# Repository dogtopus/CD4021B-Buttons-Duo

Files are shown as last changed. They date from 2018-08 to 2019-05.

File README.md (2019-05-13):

# CD4021B-Buttons-Duo

16 channel arcade button driver

(Legacy project, no longer in development)

## Features

- 16 channels
  - 8 channels for regular (NC and/or NO, depends on the software) buttons
  - 8 channels for illuminated (lamp equipped) buttons
- Programmable lamps
- Button interface are somewhat compatible with [CY-822B][1] encoder (shares
  the same electrical interface) with a better (not hard-wired to VBUS) lamp
  support.
- Separated lamp power rail (Supports 0-12V PSU, 500mA max for each channel)
- Supports 3.3V (at low speed like 1-2MHz) and 5V logic
- Supports controlling via SPI bus and bitbang with Arduino ShiftIn/ShiftOut
  code

## Usage

- Install KiCad
- Plot the board
- Zip the Gerber files and send them to whatever PCB house you like
- TODO components, BOM, etc.
- ???
- PROFIT!

PS: There's no plan for selling the assembled boards or kits at the moment,
so too bad for those who just want a working board :<

## Notes

- First and foremost, I am still very new to PCB layout and routing, so feel
  free to open an issue to give suggestions on my design and/or point out any
  mistakes I made.
- The JST connectors are rotated 180 degrees (so pin 1 is on the **right**
  side) due to a mistake I made at the very early stage of designing and the
  quickest way of fixing it is to rotate the connector.
- Make sure you are using the **"always on"** wiring suggested [here][1] (i.e.
  pin 1 is common ground, pin 2 is button and pin 3 is lamp)
  for illuminated buttons. Behavior on "illuminate on press" wiring (i.e.
  reversing pin 1 and pin 2) is undefined
  (and potentially dangerous if the lamps are powered with voltage higher or
  lower than VCC since this wiring basically shorts the lamp power to the button
  pin when the switch on the button is closed)
- The P-channel MOSFET can be swapped for cheaper alternative (e.g. CJL3415) as
  long as they have the same electrical interface, 
  the parameters (Vds, Vgs, Ids, Rds) are reasonable and proper zener diodes
  (D1-D8) and voltage divider (R1-R8, R9-R16) are chosen so that the gate of the
  MOSFET are not overdriven. (In case of CJL3415, a good choice would be 10k for
  R9-R16, 20k for R1-R8, and zeners with zener voltage of 7.5V)
  Also, TPIC6C596 can be used in place of TPIC6C595. (Tested)

[1]: https://cy-822b.blogspot.com/2016/08/the-cy-822b-usb-led-joystick-controller.html

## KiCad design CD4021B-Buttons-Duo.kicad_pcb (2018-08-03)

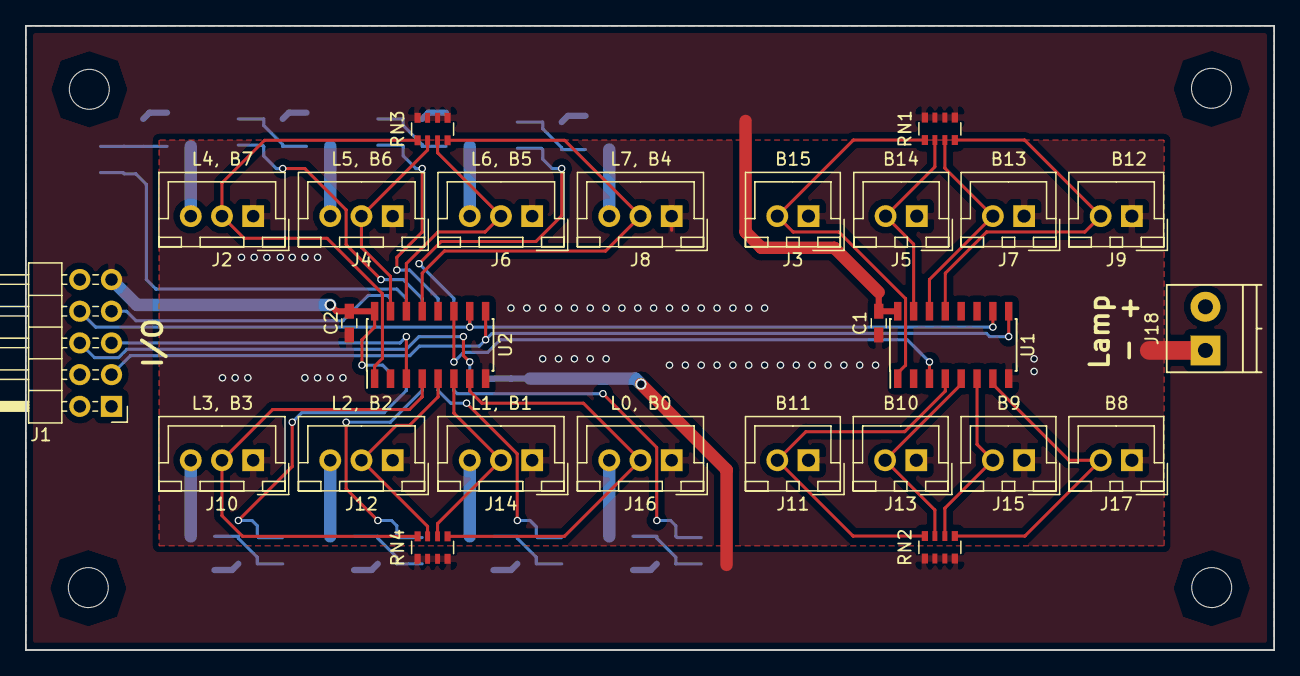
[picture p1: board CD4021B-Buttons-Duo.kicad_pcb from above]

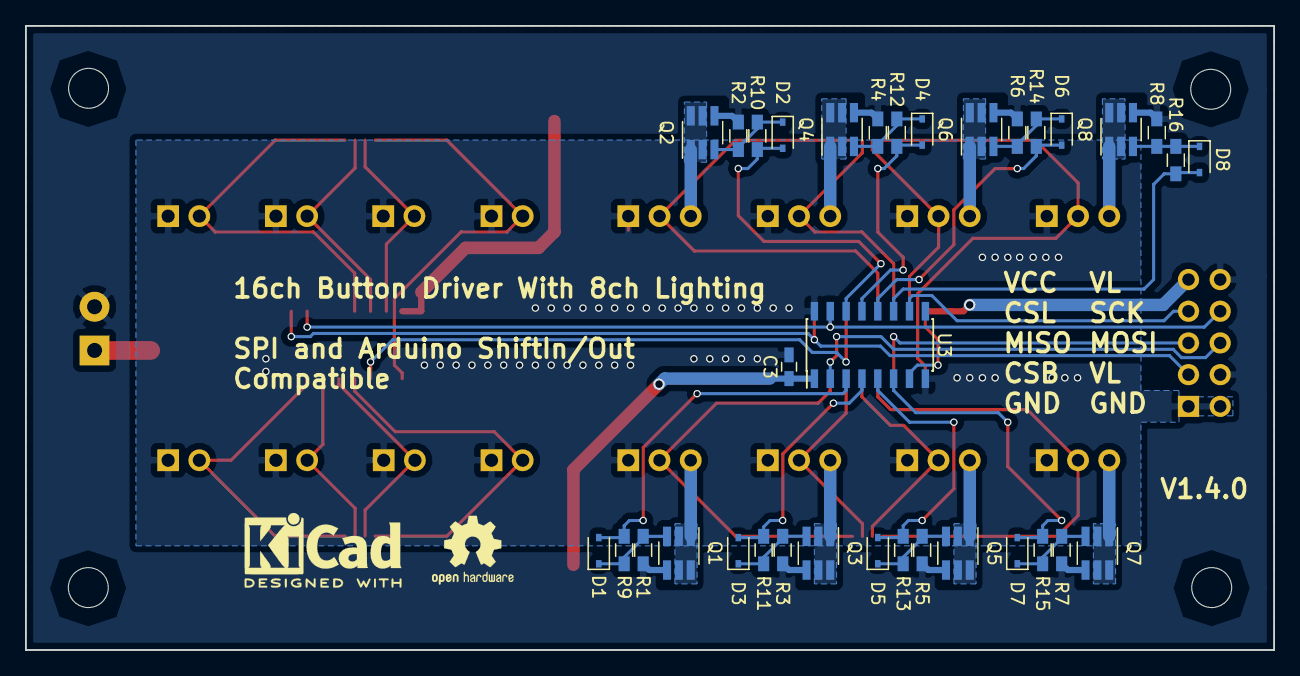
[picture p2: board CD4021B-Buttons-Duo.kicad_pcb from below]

Board: 2 copper layers, 100.0 x 50.0 mm, 60 parts (34 on the bottom side), 49 nets.

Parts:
C1, C2, C3: 100nF; C_0603_HandSoldering
D1, D2, D3, D4, D5, D6, D7, D8: Zener; D_SOD-323
J1: 2.54; Pin_Header_Angled_2x05_Pitch2.54mm
J2, J4, J6, J8, J10, J12, J14, J16: JST XH; JST_XH_B03B-XH-A_03x2.50mm_Straight
J3, J5, J7, J9, J11, J13, J15, J17: JST XH; JST_XH_B02B-XH-A_02x2.50mm_Straight
J18: 3.5; TerminalBlock_Phoenix_PT-3.5mm_2pol
Q1, Q2, Q3, Q4, Q5, Q6, Q7, Q8: IRF5806; SOT-23-6_Handsoldering
R1, R2, R3, R4, R5, R6, R7, R8: 10k; R_0603_HandSoldering
R9, R10, R11, R12, R13, R14, R15, R16: 0; R_0603_HandSoldering
RN1, RN2, RN3, RN4: 10k x4; R_Array_Convex_4x0603
U1, U2: CD4021BM; SOIC-16_3.9x9.9mm_Pitch1.27mm
U3: TPIC6C595D; SOIC-16_3.9x9.9mm_Pitch1.27mm

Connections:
+12V: J1.4, J1.10, J18.2, Q1.4, Q2.4, Q3.4, Q4.4, Q5.4, Q6.4, Q7.4, Q8.4, R1.2, R2.2, R3.2, R4.2, R5.2, R6.2, R7.2, R8.2
/CHAIN: U1.3, U2.11
/CSI: J1.3, U1.9, U2.9
/CSO: J1.7, U3.10
/D0: J16.2, RN4.5, U2.7
/D1: J14.2, RN4.6, U2.6
/D2: J12.2, RN4.7, U2.5
/D3: J10.2, RN4.8, U2.4
/D4: J8.2, RN3.4, U2.13
/D5: J6.2, RN3.3, U2.14
/D6: J4.2, RN3.2, U2.15
/D7: J2.2, RN3.1, U2.1
/D8: J17.2, RN2.5, U1.7
/D9: J15.2, RN2.6, U1.6
/D10: J13.2, RN2.7, U1.5
/D11: J11.2, RN2.8, U1.4
/D12: J9.2, RN1.4, U1.13
/D13: J7.2, RN1.3, U1.14
/D14: J5.2, RN1.2, U1.15
/D15: J3.2, RN1.1, U1.1
/L0: J16.3, Q1.1, Q1.2, Q1.5, Q1.6
/L1: J14.3, Q3.1, Q3.2, Q3.5, Q3.6
/L2: J12.3, Q5.1, Q5.2, Q5.5, Q5.6
/L3: J10.3, Q7.1, Q7.2, Q7.5, Q7.6
/L4: J8.3, Q2.1, Q2.2, Q2.5, Q2.6
/L5: J6.3, Q4.1, Q4.2, Q4.5, Q4.6
/L6: J4.3, Q6.1, Q6.2, Q6.5, Q6.6
/L7: J2.3, Q8.1, Q8.2, Q8.5, Q8.6
/LD0: D1.2, R9.1, U3.3
/LD1: D3.2, R11.1, U3.4
/LD2: D5.2, R13.1, U3.5
/LD3: D7.2, R15.1, U3.6
/LD4: D2.2, R10.1, U3.14
/LD5: D4.2, R12.1, U3.13
/LD6: D6.2, R14.1, U3.12
/LD7: D8.2, R16.1, U3.11
/MISO: J1.5, U2.3
/MOSI: J1.6, U3.2
/SCK: J1.8, U1.10, U2.10, U3.15
GND: C1.2, C2.2, C3.2, J1.1, J1.2, J2.1, J3.1, J4.1, J5.1, J6.1, J7.1, J8.1, J9.1, J10.1, J11.1, J12.1, J13.1, J14.1, J15.1, J16.1, J17.1, J18.1, U1.8, U2.8, U3.8, U3.16
unnamed: D1.1, Q1.3, R1.1, R9.2
unnamed: D2.1, Q2.3, R2.1, R10.2
unnamed: D3.1, Q3.3, R3.1, R11.2
unnamed: D4.1, Q4.3, R4.1, R12.2
unnamed: D5.1, Q5.3, R5.1, R13.2
unnamed: D6.1, Q6.3, R6.1, R14.2
unnamed: D7.1, Q7.3, R7.1, R15.2
unnamed: D8.1, Q8.3, R8.1, R16.2
VCC: C1.1, C2.1, C3.1, J1.9, RN1.5, RN1.6, RN1.7, RN1.8, RN2.1, RN2.2, RN2.3, RN2.4, RN3.5, RN3.6, RN3.7, RN3.8, RN4.1, RN4.2, RN4.3, RN4.4, U1.16, U2.16, U3.1, U3.7

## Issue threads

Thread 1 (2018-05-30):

Lower the barrier of the PMOS used

dogtopus, 2018-05-30:
Currently the circuit uses PMOSes with high |Vgs| rating (IRF5806 with Vgs of -20V to +20V). Such MOSFETs are harder to find and potentially more expensive than other MOSFETs with the same Vds but lower |Vgs| rating.

In order to achieve this, a resistor needs to be added between the PMOS gate and the corresponding DRAIN* pin on TPIC6C595.

- [x] Determine the value of the resistors and add them to the schematic
- [x] Figure out where to place the resistors on the board
- [x] Place, route and housekeeping (if needed)

Closed 2018-06-11.

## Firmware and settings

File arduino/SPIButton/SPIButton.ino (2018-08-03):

#include <SPI.h>

const SPISettings SPI596 = SPISettings(1000000, MSBFIRST, SPI_MODE0);
const SPISettings SPI4021 = SPISettings(1000000, MSBFIRST, SPI_MODE0);

const int CSL = 10;
const int CSB = 9;
// active low
uint16_t button_state = 0xffff;
uint8_t lamp_state = 0x00;

void setup() {
  // put your setup code here, to run once:
  Serial.begin(9600);
  pinMode(CSL, OUTPUT);
  pinMode(CSB, OUTPUT);
  SPI.begin();
  digitalWrite(CSB, HIGH);

  // clear lamp register
  digitalWrite(CSL, LOW);
  SPI.beginTransaction(SPI596);
  SPI.transfer(0x00);
  SPI.endTransaction();
  digitalWrite(CSL, HIGH);
}

void loop() {
  // put your main code here, to run repeatedly:

  // read button state
  digitalWrite(CSB, LOW);
  SPI.beginTransaction(SPI4021);
  button_state = SPI.transfer(0x00);
  button_state |= SPI.transfer(0x00) << 8;
  digitalWrite(CSB, HIGH);
  SPI.endTransaction();

  lamp_state = (uint8_t) button_state & 0x0f;
  // upper 4 bits of leds are mapped backwards
  lamp_state |= (uint8_t) (button_state & 0x10) << 3;
  lamp_state |= (uint8_t) (button_state & 0x20) << 1;
  lamp_state |= (uint8_t) (button_state & 0x40) >> 1;
  lamp_state |= (uint8_t) (button_state & 0x80) >> 3;
  Serial.print(button_state);
  Serial.print(" ");
  Serial.println(lamp_state);

  digitalWrite(CSL, LOW);
  SPI.beginTransaction(SPI596);
  SPI.transfer(lamp_state);
  digitalWrite(CSL, HIGH);
  SPI.endTransaction();
  delay(5);
}

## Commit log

2018-05-16 Re-place some via stitches so that they are not under silkscreens
    [CD4021B-Buttons-Duo.kicad_pcb]
2018-05-16 Enable the NC pin as an alternate lamp power pin to (hopefully) allow more current
    [CD4021B-Buttons-Duo.kicad_pcb, CD4021B-Buttons-Duo.sch]
2018-05-16 Change the pinout silkscreen
    [CD4021B-Buttons-Duo.kicad_pcb]
2018-05-16 Add open source hardware logo because why not
    [CD4021B-Buttons-Duo.kicad_pcb]
2018-05-22 Enlarge grond plane, adjust logo positioning
    [CD4021B-Buttons-Duo.kicad_pcb]
2018-05-23 Cleanup via stitches
    [CD4021B-Buttons-Duo.kicad_pcb]
2018-05-23 Change the board dimension to be exactly 100x50mm
    [CD4021B-Buttons-Duo.kicad_pcb]
2018-05-23 Move logo (again)
    [CD4021B-Buttons-Duo.kicad_pcb]
2018-05-23 Independent power connector for lamp power
    [CD4021B-Buttons-Duo.sch]
2018-05-23 Add screw terminal to the board for lamp power
    [CD4021B-Buttons-Duo.kicad_pcb, CD4021B-Buttons-Duo.sch]
2018-05-23 Re-routed using vertical-horizontal routing rule
    [CD4021B-Buttons-Duo.kicad_pcb]
2018-05-23 Minor adjustment
    [CD4021B-Buttons-Duo.kicad_pcb]
2018-05-23 Minor cleanup
    [CD4021B-Buttons-Duo.kicad_pcb]
2018-05-23 Attempt to optimize connections for bypass capacitors
    [CD4021B-Buttons-Duo.kicad_pcb]
2018-05-25 Adjust traces
    [CD4021B-Buttons-Duo.kicad_pcb]
2018-05-26 Use thinner traces for local VCC connections
    [CD4021B-Buttons-Duo.kicad_pcb]
2018-05-26 Move VCC trace for U1
    [CD4021B-Buttons-Duo.kicad_pcb]
2018-05-26 Attempt to reduce via usage on LD* traces
    [CD4021B-Buttons-Duo.kicad_pcb]
2018-05-29 Not needed anymore
    [CD4021B-Buttons-Duo.kicad_pcb]
2018-05-29 Add a demo program for Arduino
2018-05-30 Add a note about the MOSFET and TPIC6C595
2018-05-30 Add a 0ohm jumper between PMOS gate and DRAIN* pin
    [CD4021B-Buttons-Duo.sch]
2018-05-30 Map footprint
    [CD4021B-Buttons-Duo.sch]
2018-05-31 Add zener on PMOS gates for extra assurance
    [CD4021B-Buttons-Duo.sch]
2018-06-11 Switch the pad connection of VCC planes back to thermal relief
    [CD4021B-Buttons-Duo.kicad_pcb]
2018-06-11 Add voltage divider to the PMOS gate on the board
    [CD4021B-Buttons-Duo.kicad_pcb]
2018-06-11 The anode of the zener should be connected to the DRAIN* pin instead of GND
    Otherwise the MOSFET always conducts
    [CD4021B-Buttons-Duo.kicad_pcb, CD4021B-Buttons-Duo.sch]
2018-06-18 Cleanup: Make LD7 completely on the back side
    [CD4021B-Buttons-Duo.kicad_pcb]
2018-07-16 Update to KiCad 5.0
    [CD4021B-Buttons-Duo.kicad_pcb, CD4021B-Buttons-Duo.sch]
2018-07-24 Change CSI/CSO to CSB (button)/CSL (lamp) to avoid confusion
    [CD4021B-Buttons-Duo.kicad_pcb]
2018-08-03 Set aux axis origin to the top left corner of the board
    [CD4021B-Buttons-Duo.kicad_pcb]
2018-09-16 Fix symbol problem, again.
    [CD4021B-Buttons-Duo.sch]
